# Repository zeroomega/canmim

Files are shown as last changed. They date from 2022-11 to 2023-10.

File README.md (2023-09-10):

# CAN Man In the Middle (CANMIM)

CANMIM is a DIY project which supports reading from vehicle's CAN bus, filtering and injecting data and sending the CAN data to another CAN bus using a ESP32C3 MCU and MP2515 CAN controller. The way it works is very similar to the Man In the Middle attack. The project uses ESP-IDF.

# Intended use case

For amateur car racer and track enthusists, it is very popular to use laptimer and data loggers like AIM Solo 2 DL to log GPS and CAN data. However, these comercial data loggers/lap timers usually cannot log any data that are not from the CAN bus. For example, aftermarket oil pressure sensor sends out 0-5V analog signals and there isn't any official accessories that can hook it up to an AIM Solo 2 DL device. This CANMIM device solved this issue, by reading the analog signal from the oil pressure sensor using MCU's ADC controller, send out the ADC readings using custom CAN IDs, combined with CAN data from the vehicle's CAN bus, to data logger's CAN input.

This project is currently designed for Toyota GR86/Subaru BRZ ZD8. But the code is simple and should be easy to port for other vehicles.

# Recommended parts list

For using the PCB provided in this repo, following parts will be needed to assemble a unit:

* [ESP32-C3-DevKitC-02](https://www.amazon.com/gp/product/B09D3S4RPZ)
* [MCP2515 CAN Bus Module TJA1050 Receiver SPI Module](https://www.amazon.com/gp/product/B01D0WSEWU)
* [SN65HVD230 CAN Bus Transceiver breakout board](https://www.amazon.com/gp/product/B0B82GJLH5)
* [Traco TSR-1-2450 5V1A buck converter](https://www.digikey.com/en/products/detail/traco-power/TSR-1-2450/9383780)
* [Through hole Resistors (recommend 10KOhm and 22KOhm)](https://www.amazon.com/gp/product/B072BL2VX1)
* [JST XH connectors](https://www.amazon.com/gp/product/B09DBGVX5C)
  - [Optional RJ45 connectors](https://lcsc.com/product-detail/Ethernet-Connectors-Modular-Connectors-RJ45-RJ11_CONNFLY-Elec-DS1129-05-S80BP-X_C86580.html)

TODO: Explain how to assemble a unit.

# Build the project

This projects requires ESP-IDF to build. Please fetch the latest version from [Espressif](https://dl.espressif.com/dl/esp-idf/).

## Fetch the source and setup the environment

```
git clone --recurse-submodules https://github.com/zeroomega/canmim
```

Please follow the guide at https://docs.espressif.com/projects/esp-idf/en/v4.3.1/esp32/get-started/index.html#get-started-set-up-env to setup the enviroment. On Windows, this can be done by opening up a ESP-IDF powershell windows.

## Setup and build the project

```
cd canmim
idf.py set-target esp32c3
idf.py build
```

# Flash the image to the MCU

Connect the MCU to the computer using USB. Find the device name of the MCU serial device, e.g. COM8 on Windows. Run:

```
idf.py -p COM8 flash
```

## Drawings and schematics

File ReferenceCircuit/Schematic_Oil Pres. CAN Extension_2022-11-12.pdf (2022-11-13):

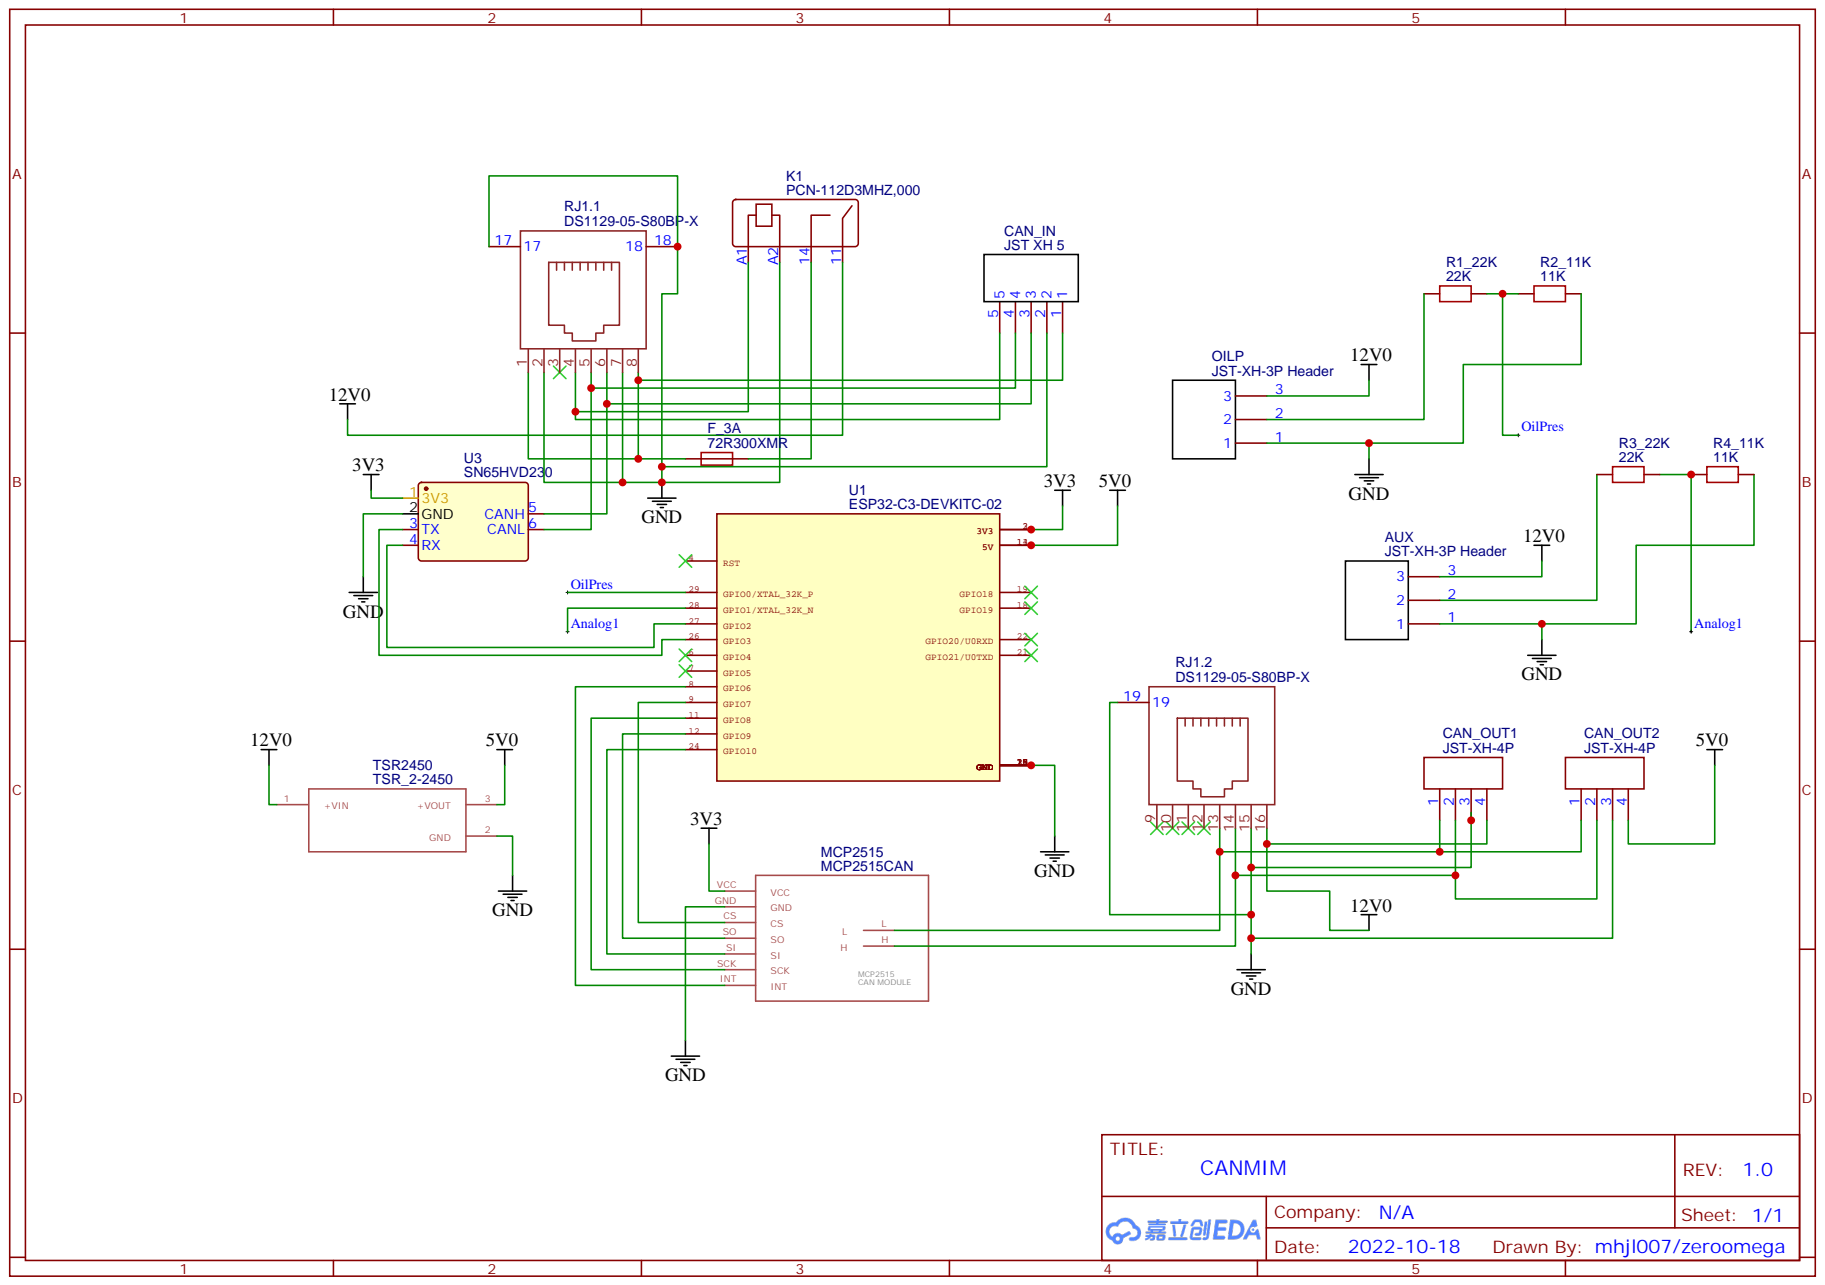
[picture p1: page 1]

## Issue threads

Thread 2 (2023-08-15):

Compatible with Racecapture MK3 Track?

xShingox, 2023-08-15:
Hello, I apologize if this isnt the right way to contact you or ask questions.

I have a racecapture Mk3 and I'd like to install an oil pressure sensor on my 23' BRZ.

I was pointed this direction by "900BRZ's" youtube channel [https://www.youtube.com/watch?v=4Jk5WTWoqt4]

Question - is this compatible with race capture mk3? The MK3 Track is only able to capture CAN signals so I assume yes as long as I find a way to get the CANID properly? This is somewhat out of my realm of knowledge now.

barm, 2023-08-30:
Hi, it should work fine since this injects the value directly into the CAN feed. You’d just need to add the CAN ID to your profile. Here’s the ID: `0x662` and the pressure value is the first byte.

https://github.com/zeroomega/canmim/blob/1c6063e5c3e2694a2d1225b56ae2204972e29282/main/board_config.h#L23

https://github.com/zeroomega/canmim/blob/1c6063e5c3e2694a2d1225b56ae2204972e29282/main/main.cpp#L455

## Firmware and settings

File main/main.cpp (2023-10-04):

#include "sdkconfig.h"
#include "board_config.h"
#include "esp_mac.h"
#include "freertos/FreeRTOS.h"
#include "freertos/task.h"
#include "freertos/queue.h"
#include "freertos/semphr.h"
#include "esp_adc/adc_cali_scheme.h"
#include "esp_adc/adc_continuous.h"
#include "esp_system.h"
#include "esp_chip_info.h"
#include "esp_flash.h"
#include "esp_timer.h"
#include "esp_log.h"
#include "nvs_flash.h"
#include "driver/gpio.h"
#include "driver/twai.h"
#include "driver/rmt.h"

#include <stdio.h>
#include <string.h>

#include "canmim.h"
#include "mcp2515.h"
#include "led_strip.h"
#include "ble.h"

#define LOG_CAN_TAG "CAN"
#define LOG_MCU_TAG "MCU"
#define LOG_CAN_SPI_TAG "SPI CAN"
#define LOG_BLE_TAG "BLE"

#define ADC_FRAME_SIZE 4 * 100

// Global SPI Handle for MCP2515 Can Controller
spi_device_handle_t spi_mcp2515;
adc_cali_handle_t adc1_cali_handle = NULL;
adc_continuous_handle_t adc1_cont_handle = NULL;
MCP2515 *mcpCan = nullptr;


QueueHandle_t spiLock;
QueueHandle_t canOutputQueue;
QueueHandle_t bleOutputQueue;
QueueHandle_t spiCanIntrQueue;

volatile bool shouldUpdateADC = false;

#ifdef CANMIM_PRINT_METRICS

volatile size_t CAN_IN_COUNT = 0;
volatile size_t CAN_OUT_COUNT = 0;
volatile size_t BLE_OUT_COUNT = 0;
volatile size_t BLE_NOTIFIED_COUNT = 0;
volatile int64_t MCP_TIMER = 0;
volatile uint32_t ADC0_MV = 0;
volatile uint32_t ADC1_MV = 0;

#endif

bool can_isolation = false;

void gpio_init();

void incomingCANTask(void *pvParameter);

void outgoingCANTask(void *pvParameter);

void spiCanTask(void *pvParameter);

void bleTask(void *pvParameter);

void set_ble_name_from_mac();

// Helper function to cause system reboot when fatal error happens.
void fatal_error();

// Helper function to initiate ADC. Will reboot if error happens.
void init_adc();

// Helper function to initiate SPI Master controller. Will reboot if error
// happens.
void init_spi();

// Helper function to initiate ESP32 CAN Controller.
void init_can();

void print_mcu_info();

void set_led();

void update_adc(uint32_t *adc1_mv, uint32_t *adc2_mv);

uint16_t calc_oil_pressure(uint32_t adc_mv);

void send_adc_data_to_can(uint32_t adc0_mv, uint32_t adc1_mv);

void handling_incoming_message();

static bool IRAM_ATTR s_conv_done_cb(adc_continuous_handle_t handle, const adc_continuous_evt_data_t *edata, void *user_data)
{
    shouldUpdateADC = true;
    return true;
}

#ifdef CANMIM_PRINT_METRICS

static void tick_timer_cb(void *arg)
{
    size_t can_in_count = CAN_IN_COUNT;
    size_t can_out_count = CAN_OUT_COUNT;
    size_t ble_out_count = BLE_OUT_COUNT;
    size_t ble_notified_count = BLE_NOTIFIED_COUNT;
    int64_t mcp_timer = MCP_TIMER;
    ESP_LOGI("TIMER", "can_in_count: %zu", can_in_count);
    ESP_LOGI("TIMER", "can_out_count: %zu", can_out_count);
    ESP_LOGI("TIMER", "ble_out_count: %zu", ble_out_count);
    ESP_LOGI("TIMER", "ble_notified_count: %zu", ble_notified_count);
    ESP_LOGI("TIMER", "MCP_TIMER: %zu microsec", (size_t)mcp_timer);
    ESP_LOGI("TIMER", "Sample, %" PRIi32 " mV %" PRIi32 " mV", ADC0_MV, ADC1_MV);
    ESP_LOGI("TIMER", "");
    CAN_IN_COUNT = 0;
    CAN_OUT_COUNT = 0;
    BLE_OUT_COUNT = 0;
    BLE_NOTIFIED_COUNT = 0;
    MCP_TIMER = 0;
}

#endif

extern "C" void app_main(void)
{
    gpio_init();
    print_mcu_info();
    if (can_isolation)
        ESP_LOGI(LOG_CAN_TAG, "CAN isolation: enabled");
    else
        ESP_LOGI(LOG_CAN_TAG, "CAN isolation: disabled");
    init_can();
    if (can_isolation)
    {
        init_spi();
        spiLock = xSemaphoreCreateMutex();
        ESP_LOGI(LOG_MCU_TAG, "SPI Init");
        printf("SPI Init\n");
    }
    init_adc();
    ESP_LOGI(LOG_MCU_TAG, "ADC Init");
    set_led();
    ESP_LOGI(LOG_MCU_TAG, "LED Init");

    // Init NVS, which is used by WiFi and BLE stack.
    esp_err_t ret = nvs_flash_init();
    if (ret == ESP_ERR_NVS_NO_FREE_PAGES || ret == ESP_ERR_NVS_NEW_VERSION_FOUND)
    {
        ESP_ERROR_CHECK(nvs_flash_erase());
        ret = nvs_flash_init();
    }
    ESP_ERROR_CHECK(ret);
    set_ble_name_from_mac();
#ifdef CANMIM_PRINT_METRICS
    const esp_timer_create_args_t tick_timer_args = {
        .callback = &tick_timer_cb,
        .arg = NULL,
        .dispatch_method = ESP_TIMER_TASK,
        .name = "tick_timer",
        .skip_unhandled_events = false,
    };

    esp_timer_handle_t tick_timer = NULL;
    ESP_ERROR_CHECK(esp_timer_create(&tick_timer_args, &tick_timer));
    ESP_ERROR_CHECK(esp_timer_start_periodic(tick_timer, 1000000));
#endif

    canOutputQueue = xQueueCreate(50, sizeof(can_frame_t));
    bleOutputQueue = xQueueCreate(50, sizeof(can_frame_t));

    xTaskCreate(incomingCANTask, "incomingCANTask", 4096, NULL, 1, NULL);
    xTaskCreate(outgoingCANTask, "outgoingCANTask", 4096, NULL, 3, NULL);
    if (can_isolation)
        xTaskCreate(spiCanTask, "spiCanTask", 4096, NULL, 3, NULL);
    xTaskCreate(bleTask, "bleTask", 4096, NULL, 2, NULL);
}

void set_ble_name_from_mac()
{
    uint8_t ble_mac[8];
    memset(ble_mac, 0, sizeof(ble_mac));
    esp_err_t ret = esp_read_mac(ble_mac, ESP_MAC_BT);
    if (ret != ESP_OK)
    {
        ESP_LOGE(LOG_MCU_TAG, "Failed to retrieve BLE MAC address: %d", ret);
    }
    char ble_name[32];
    memset(ble_name, 0, sizeof(ble_name));
    size_t ble_name_len = strlen(BLE_DEVICE_NAME_BASE);
    if (ble_name_len > sizeof(ble_name) - 4)
        ble_name_len = sizeof(ble_name) - 4;
    memcpy(ble_name, BLE_DEVICE_NAME_BASE, ble_name_len);
    int char_count = sprintf(ble_name + ble_name_len, "_%02X%02X", ble_mac[4], ble_mac[5]);
    ble_name_len += char_count;
    ble_name[ble_name_len] = 0;
    set_ble_name(ble_name, ble_name_len);
    ESP_LOGI(LOG_BLE_TAG, "BLE Device name: %s", ble_name);
}

static void IRAM_ATTR can_int_handler(void *arg) {
    int dummy = 0;
    xQueueSendFromISR(spiCanIntrQueue, &dummy, NULL);
}

void gpio_init()
{
    // Set MCP2525 interrupt pin to float as we don't use it
    // for now.
    if (MCP_INT != -1) {
        gpio_config_t io_conf;
        memset(&io_conf, 0, sizeof(gpio_config_t));
        io_conf.intr_type = GPIO_INTR_NEGEDGE;
        io_conf.pin_bit_mask = 1ULL << MCP_INT;
        io_conf.mode = GPIO_MODE_INPUT;
        io_conf.pull_down_en = GPIO_PULLDOWN_ENABLE;
        gpio_config(&io_conf);
        gpio_install_isr_service(0);
        gpio_isr_handler_add((gpio_num_t)MCP_INT, can_int_handler, NULL);
        spiCanIntrQueue = xQueueCreate(10, sizeof(int));
    }

#ifndef ISO_OVERRIDE
    if (ISO_PIN != -1)
    {
        esp_err_t err = gpio_set_direction((gpio_num_t)ISO_PIN, GPIO_MODE_INPUT_OUTPUT);
        if (err != ESP_OK)
        {
            ESP_LOGE("GPIO", "ISO Pin failed to set to I/O mode, error code: %d", err);
        }
        err = gpio_set_pull_mode((gpio_num_t)ISO_PIN, GPIO_PULLUP_ONLY);
        if (err != ESP_OK)
        {
            ESP_LOGE("GPIO", "ISO Pin failed to set to Pull Up, error code: %d", err);
        }
        vTaskDelay(50 / portTICK_PERIOD_MS);
        int level = gpio_get_level((gpio_num_t)ISO_PIN);
        if (level) {
            // Switch is ON
            can_isolation = false;
            ESP_LOGI("GPIO", "ISO Pin is 1");
        }
        else {
            // Switch is OFF
            can_isolation = true;
            ESP_LOGI("GPIO", "ISO Pin is 0");
        }
    }
#else
    can_isolation = ISO_OVERRIDE;
#endif
}

void print_mcu_info()
{
    /* Print chip information */
    esp_chip_info_t chip_info;
    esp_chip_info(&chip_info);
    printf("This is %s chip with %d CPU core(s), WiFi%s%s, ",
           CONFIG_IDF_TARGET,
           chip_info.cores,
           (chip_info.features & CHIP_FEATURE_BT) ? "/BT" : "",
           (chip_info.features & CHIP_FEATURE_BLE) ? "/BLE" : "");

    printf("silicon revision %" PRIi16 ", ", chip_info.revision);

    uint32_t size_flash_chip;
    esp_flash_get_size(NULL, &size_flash_chip);
    printf("%ldMB %s flash\n", size_flash_chip / (1024 * 1024),
           (chip_info.features & CHIP_FEATURE_EMB_FLASH) ? "embedded" : "external");

    printf("Minimum free heap size: %ld bytes\n", esp_get_minimum_free_heap_size());
}

bool IsPassthroughID(twai_message_t *message)
{
    // for (int i = 0; i < sizeof(kPassthroughIDs)/sizeof(uint32_t); i++) {
    //     if (kPassthroughIDs[i] == message->identifier)
    //         return true;
    // }
    // return false;
    // For GT86, since we don't have a full list of CAN ID that datalogger listens to
    // let all CAN IDs pass through.
    return true;
}

void fatal_error()
{
    for (int i = 10; i >= 0; i--)
    {
        printf("Restarting in %d seconds...\n", i);
        vTaskDelay(1000 / portTICK_PERIOD_MS);
    }
    printf("Restarting now.\n");
    fflush(stdout);
    esp_restart();
}

void init_adc()
{
    adc_cali_curve_fitting_config_t cali_config = {
        .unit_id = ADC_UNIT_1,
        .atten = ADC_ATTEN_DB_11,
        .bitwidth = ADC_BITWIDTH_12,
    };

    esp_err_t ret;
    ret = adc_cali_create_scheme_curve_fitting(&cali_config, &adc1_cali_handle);
    if (ret != ESP_OK)
    {
        ESP_LOGE("ADC", "adc cali failed, code %d", ret);
        fatal_error();
    }

    adc_continuous_handle_cfg_t adc_config = {
        .max_store_buf_size = 4 * 5000,
        .conv_frame_size = ADC_FRAME_SIZE,
    };
    ESP_ERROR_CHECK(adc_continuous_new_handle(&adc_config, &adc1_cont_handle));

    adc_digi_pattern_config_t adc_pattern[2];
    memset(&adc_pattern, 0, sizeof(adc_digi_pattern_config_t) * 2);
    for (int i = 0; i < 2; i++)
    {
        adc_pattern[i].atten = ADC_ATTEN_DB_11;
        adc_pattern[i].channel = i;
        adc_pattern[i].unit = ADC_UNIT_1;
        adc_pattern[i].bit_width = ADC_BITWIDTH_12;
    }
    adc_continuous_config_t dig_cfg = {
        .pattern_num = 2,
        .adc_pattern = adc_pattern,
        .sample_freq_hz = 2 * 1000,
        .conv_mode = ADC_CONV_SINGLE_UNIT_1,
        .format = ADC_DIGI_OUTPUT_FORMAT_TYPE2,
    };

    ESP_ERROR_CHECK(adc_continuous_config(adc1_cont_handle, &dig_cfg));
    adc_continuous_evt_cbs_t cbs = {
        .on_conv_done = s_conv_done_cb,
        .on_pool_ovf = NULL};
    ESP_ERROR_CHECK(adc_continuous_register_event_callbacks(adc1_cont_handle, &cbs, NULL));
}

void init_spi()
{
    spi_bus_config_t s_bus_config;
    memset(&s_bus_config, 0, sizeof(spi_bus_config_t));
    s_bus_config.mosi_io_num = MCP_MOSI;
    s_bus_config.miso_io_num = MCP_MISO;
    s_bus_config.sclk_io_num = MCP_SCK;
    s_bus_config.quadwp_io_num = -1;
    spi_device_interface_config_t s_dev_config;
    memset(&s_dev_config, 0, sizeof(spi_device_interface_config_t));
    s_dev_config.clock_speed_hz = 8 * 1000 * 1000; // 8Mhz SPI
    s_dev_config.mode = 0;
    s_dev_config.spics_io_num = MCP_CS;
    s_dev_config.queue_size = 10;
    esp_err_t ret_code = spi_bus_initialize(SPI2_HOST, &s_bus_config, SPI_DMA_CH_AUTO);
    if (ret_code != ESP_OK)
    {
        ESP_LOGE("SPI", "Failed to initialize SPI Bus, Error: %s", esp_err_to_name(ret_code));
        fatal_error();
    }
    else
    {
        ESP_LOGW("SPI", "SPI bus initialized");
    }

    ret_code = spi_bus_add_device(SPI2_HOST, &s_dev_config, &spi_mcp2515);
    if (ret_code != ESP_OK)
    {
        ESP_LOGE("SPI", "Failed to initialize SPI Device, Error: %s", esp_err_to_name(ret_code));
        fatal_error();
    }
    else
    {
        ESP_LOGW("SPI", "SPI device added");
    }
}

void init_can()
{
    // Initialize configuration structures using macro initializers
    twai_mode_t mode = TWAI_MODE_LISTEN_ONLY;
    if (!can_isolation)
        mode = TWAI_MODE_NO_ACK;
    twai_general_config_t g_config = TWAI_GENERAL_CONFIG_DEFAULT((gpio_num_t)CAN_TX /* TX */, (gpio_num_t)CAN_RX /* RX */, mode);
    twai_timing_config_t t_config = TWAI_TIMING_CONFIG_500KBITS();
    twai_filter_config_t f_config = TWAI_FILTER_CONFIG_ACCEPT_ALL();
    // Install TWAI driver
    if (twai_driver_install(&g_config, &t_config, &f_config) == ESP_OK)
    {
        ESP_LOGW("ESPCAN", "Can bus driver installed");
    }
    else
    {
        ESP_LOGE("ESPCAN", "Failed to install driver");
        fatal_error();
    }
    if (twai_start() == ESP_OK)
    {
        ESP_LOGW("ESPCAN", "Can bus started");
    }
    else
    {
        ESP_LOGE("ESPCAN", "Failed to start");
        fatal_error();
    }
}

uint16_t calc_oil_pressure(uint32_t adc_mv)
{
    if (adc_mv < OIL_PRESSURE_VL)
        adc_mv = 0;
    else
        adc_mv -= OIL_PRESSURE_VL;
    adc_mv = adc_mv * OIL_PRESSURE_PMAX * 10 / (OIL_PRESSURE_VH - OIL_PRESSURE_VL);
    return (uint16_t)adc_mv;
}

void update_adc(uint32_t *adc0_mv, uint32_t *adc1_mv)
{
    static uint8_t result[ADC_FRAME_SIZE * 2] = {0};

    uint32_t adc_sum[2];
    adc_sum[0] = 0;
    adc_sum[1] = 0;
    uint32_t adc_read_count[2];
    adc_read_count[0] = 0;
    adc_read_count[1] = 0;

    uint32_t ret_num = 0;
    esp_err_t ret;
    ret = adc_continuous_read(adc1_cont_handle, result, ADC_FRAME_SIZE * 2, &ret_num, 0);
    if (ret != ESP_OK)
    {
        ESP_LOGI("ADC", "ADC read return non OK: %d\n", ret);
    }
    for (int i = 0; i < ret_num; i += SOC_ADC_DIGI_RESULT_BYTES)
    {
        adc_digi_output_data_t *p = (adc_digi_output_data_t *)&result[i];
        uint32_t chan_num = p->type2.channel;
        if (chan_num != 0 && chan_num != 1)
        {
            ESP_LOGE("ADC", "Unknown ADC channel number %" PRIi32, chan_num);
            fatal_error();
        }
        uint32_t data = p->type2.data;
        adc_sum[chan_num] += data;
        adc_read_count[chan_num]++;
    }
    for (int i = 0; i < 2; i++)
    {
        if (adc_read_count[i] > 0)
            adc_sum[i] /= adc_read_count[i];
        int mV = 0;
        adc_cali_raw_to_voltage(adc1_cali_handle, adc_sum[i], &mV);
        if (mV >= 0)
            adc_sum[i] = mV;
        else
            adc_sum[i] = 0;
    }
    *adc0_mv = adc_sum[0] * (OIL_PRESSURE_R1 + OIL_PRESSURE_R2) / OIL_PRESSURE_R1;
    *adc1_mv = adc_sum[1] * (OIL_PRESSURE_R1 + OIL_PRESSURE_R2) / OIL_PRESSURE_R1;

#ifdef CANMIM_PRINT_METRICS
    ADC0_MV = *adc0_mv;
    ADC1_MV = *adc1_mv;
#endif
}

void send_adc_data_to_can(uint32_t adc0_mv, uint32_t adc1_mv)
{
    uint16_t pressure0 = calc_oil_pressure(adc0_mv);
    uint16_t pressure1 = calc_oil_pressure(adc1_mv);
    can_frame_t frame;
    memset(&frame, 0, sizeof(can_frame_t));
    frame.timestamp = esp_timer_get_time() / 1000;
    frame.can_id = OIL_PRESSURE_CAN_ID;
    frame.can_dlc = 8;
    frame.data[0] = pressure0 & 0xFF;
    frame.data[1] = (pressure0 >> 8) & 0xFF;
    frame.data[2] = pressure1 & 0xFF;
    frame.data[3] = (pressure1 >> 8) & 0xFF;
    frame.data[4] = adc0_mv & 0xFF;
    frame.data[5] = (adc0_mv >> 8) & 0xFF;
    frame.data[6] = adc1_mv & 0xFF;
    frame.data[7] = (adc1_mv >> 8) & 0xFF;
    if (xQueueSend(canOutputQueue, &frame, 0) != pdTRUE)
    {
        ESP_LOGE("ADC", "Output CAN Queue Full");
    }

    if (xQueueSend(bleOutputQueue, &frame, 0) != pdTRUE)
    {
        ESP_LOGE("ADC", "Output BLE Queue Full");
    }
}

void handling_incoming_message()
{
    twai_message_t message;
    can_frame_t frame;
    esp_err_t ret_code;
    ret_code = twai_receive(&message, 1);
    switch (ret_code)
    {
    case ESP_OK:
        if (!(message.rtr))
        {
            frame.timestamp = esp_timer_get_time() / 1000;
            CAN_IN_COUNT++;
            frame.can_id = message.identifier;
            frame.can_dlc = message.data_length_code;
            memcpy(frame.data, message.data, 8);
            if (can_isolation)
                xQueueSend(canOutputQueue, &frame, 0);
            xQueueSend(bleOutputQueue, &frame, 0);
        }
        break;
    case ESP_ERR_TIMEOUT:
        // Timeout is normal when there is no CAN communication.
        // Ignore it.
        break;
    default:
        ESP_LOGE("ESPCAN", "Failed when receiving due to %s", esp_err_to_name(ret_code));
    }
}

void set_led()
{
    static led_strip_t *pStrip_a;
    pStrip_a = led_strip_init(RMT_CHANNEL_0, LED_PIN, 1);
    pStrip_a->clear(pStrip_a, 50);
    vTaskDelay(50 / portTICK_PERIOD_MS);
    pStrip_a->set_pixel(pStrip_a, 0, 6, 10, 6);
    pStrip_a->refresh(pStrip_a, 100);
}

void incomingCANTask(void *pvParameter)
{
    // Start ADC measurement.
    ESP_ERROR_CHECK(adc_continuous_start(adc1_cont_handle));

    for (;;)
    {
        uint32_t adc0_mv, adc1_mv;
        if (shouldUpdateADC)
        {
            shouldUpdateADC = false;
            update_adc(&adc0_mv, &adc1_mv);
            send_adc_data_to_can(adc0_mv, adc1_mv);
        }
        handling_incoming_message();
    }
}

void outgoingCANTask(void *pvParameter)
{
    if (can_isolation)
    {
        if (xSemaphoreTake(spiLock, portMAX_DELAY) != pdTRUE) {
            ESP_LOGE("SPI", "Cannot obtaine SPI Lock");
            fatal_error();
        }
        mcpCan = new MCP2515(&spi_mcp2515);
        printf("Created MCP2515 object\n");
        mcpCan->setInterruptMask(MCP2515::CANINTF_RX0IF | MCP2515::CANINTF_RX1IF);
        mcpCan->reset();
        printf("Reset MCP2515 \n");
        mcpCan->setBitrate(CAN_500KBPS, MCP_8MHZ);
        printf("Set bitrate MCP2515 \n");
        mcpCan->setNormalMode();
        printf("Set Normal mode MCP2515 \n");
        MCP2515::ERROR err = mcpCan->setOneShotMode(true);
        xSemaphoreGive(spiLock);
        if (err != MCP2515::ERROR_OK)
        {
            ESP_LOGE("MCP2515", "Failed to set One Shot Mode");
        }
        else
        {
            ESP_LOGI("MCP2515", "Set One Shot Mode");
        }
    }
    can_frame_t frame;
    for (;;)
    {
        if (xQueueReceive(canOutputQueue, &frame, portMAX_DELAY) == pdTRUE)
        {
            // Unlikely to happen. If Output CAN is congested, drop a few CAN
            // frames to avoid buffer overfill.
            if (uxQueueMessagesWaiting(canOutputQueue) > 25)
            {
                for (int i = 0; i < 10; i++)
                {
                    xQueueReceive(bleOutputQueue, &frame, portMAX_DELAY);
                }
                ESP_LOGI("MCPCAN", "Skipped 10 messages");
            }

            if (can_isolation)
            {
                CAN_OUT_COUNT++;
                can_frame mcp_frame;
                mcp_frame.can_id = frame.can_id;
                mcp_frame.can_dlc = frame.can_dlc;
                memcpy(mcp_frame.data, frame.data, CAN_MAX_DATALEN);
                int64_t begin = esp_timer_get_time();
                if (xSemaphoreTake(spiLock, portMAX_DELAY) != pdTRUE)
                    continue;
                MCP2515::ERROR err = mcpCan->sendMessageSkipStatus(&mcp_frame);
                xSemaphoreGive(spiLock);
                int64_t end = esp_timer_get_time();
                MCP_TIMER = (end - begin);
                if (err != MCP2515::ERROR_OK)
                {
                    ESP_LOGE("MCPCAN", "Failed sending to CAN %d", err);
                    if (err == MCP2515::ERROR_ALLTXBUSY)
                    {
                        ESP_LOGE("MCPCAN", "Failed sending to CAN, All TX busy");
                    }
                }
            }
            else
            {
                CAN_OUT_COUNT++;
                twai_message_t message;
                memset(&message, 0, sizeof(message));
                message.identifier = frame.can_id;
                message.data_length_code = frame.can_dlc;
                memcpy(message.data, frame.data, 8);
                esp_err_t ret_code = twai_transmit(&message, 1);
                if (ret_code != ESP_OK)
                    ESP_LOGE("ESPCAN", "Failed when transmitting due to %s", esp_err_to_name(ret_code));
            }
        }
    }
}

void spiCanTask(void *pvParameter) {
    for(;;) {
        int dummy;
        can_frame mcp_frame;
        can_frame_t frame;
        memset(&frame, 0, sizeof(can_frame_t));
        if (xQueueReceive(spiCanIntrQueue, &dummy, 20) == pdTRUE) {
            // INT pin interrupt received.
            if (mcpCan == nullptr)
                continue;
            if (xSemaphoreTake(spiLock, portMAX_DELAY) != pdTRUE)
                continue;
            uint8_t intr = mcpCan->getInterrupts();
            if (intr & MCP2515::CANINTF_RX0IF) {
                MCP2515::ERROR err = mcpCan->readMessage(MCP2515::RXB0, &mcp_frame);
                if (err != MCP2515::ERROR::ERROR_OK) {
                    ESP_LOGE("MCP", "Receive error: %d", (int)err);
                } else {
                    frame.can_dlc = mcp_frame.can_dlc;
                    frame.can_id =  mcp_frame.can_id;
                    memcpy(mcp_frame.data, frame.data, CAN_MAX_DATALEN);
                    xQueueSend(bleOutputQueue, &frame, 0);
                }

            }
            if (intr & MCP2515::CANINTF_RX1IF) {
                MCP2515::ERROR err = mcpCan->readMessage(MCP2515::RXB1, &mcp_frame);
                if (err != MCP2515::ERROR::ERROR_OK) {
                    ESP_LOGE("MCP", "Receive error: %d", (int)err);
                } else {
                    frame.can_dlc = mcp_frame.can_dlc;
                    frame.can_id =  mcp_frame.can_id;
                    memcpy(mcp_frame.data, frame.data, CAN_MAX_DATALEN);
                    xQueueSend(bleOutputQueue, &frame, 0);
                }
            }
            xSemaphoreGive(spiLock);
        }
    }
}

void bleTask(void *pvParameter)
{
    ble_init();
    can_frame_t frame;
    while (1)
    {
        if (xQueueReceive(bleOutputQueue, &frame, portMAX_DELAY) == pdTRUE)
        {
            if (uxQueueMessagesWaiting(bleOutputQueue) > 25)
            {
                for (int i = 0; i < 10; i++)
                {
                    xQueueReceive(bleOutputQueue, &frame, portMAX_DELAY);
                }
                ESP_LOGI("BLE", "10 message skipped.");
            }
            BLE_OUT_COUNT++;
            if (ble_notify(&frame))
            {
                BLE_NOTIFIED_COUNT++;
            }
        }
    }
}

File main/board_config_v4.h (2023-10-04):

#ifndef _BOARD_CONFIG_V4_H_
#define _BOARD_CONFIG_V4_H_

// SPI PIN Map
#define MCP_SCK   7
#define MCP_MOSI 10
#define MCP_MISO  8
#define MCP_CS    9
#define MCP_INT   6

// Isolation Control PIN
#define ISO_PIN   5
// #define ISO_OVERRIDE 1

// CAN Controller PIN Map
#define CAN_TX    3
#define CAN_RX    2

// LED PIN Map
#define LED_PIN   4

// CAN ID for OIL Pressure
#define OIL_PRESSURE_CAN_ID 0x662

// Resistors value in kOhm for the voltage divider.
#define OIL_PRESSURE_R1 10
#define OIL_PRESSURE_R2 20

// Characteristics of the oil pressure sensor.
// Voltage in mV.
#define OIL_PRESSURE_VL 500
#define OIL_PRESSURE_VH 4500
#define OIL_PRESSURE_PMAX 150

// Define CANMIM_PRINT_METRICS to print sample data every second to log
#define CANMIM_PRINT_METRICS

#define BLE_DEVICE_NAME_BASE "ECAN"

#endif

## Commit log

2022-10-14 Add oil pressure readings
2022-11-12 Update ReadMe and fix some comments issues.
    [main.cpp]
2022-11-13 Fix a typo and add PCB design
    [Drill_NPTH_Through.DRL, Drill_PTH_Through.DRL, Drill_PTH_Through_Via.DRL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]
2023-02-17 Add onboard LED control
2023-02-28 Support IDF 5
    Add support to ESP-IDF5. Project will no longer build under IDF 4
    [main.cpp]
2023-02-28 Fix CAN bus message sampling
    [main.cpp]
2023-02-28 Fix ADC function signature
    [main.cpp]
2023-03-01 Add CAN frame rate profiling
2023-07-22 CAN and BLE improvements
    This patch add timestamp to CAN frame. The BLE module now handles the
    RaceChrono interval command.
2023-09-15 Add support to board configuration v4_sense
2023-09-16 Change pressure output to 16bit unsigned integer
2023-10-04 Fix isolation control pin detection.
    [board_config_v4.h, main.cpp]
